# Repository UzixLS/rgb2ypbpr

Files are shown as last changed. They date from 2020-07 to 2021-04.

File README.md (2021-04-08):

## RGB to YPbPr simple converter

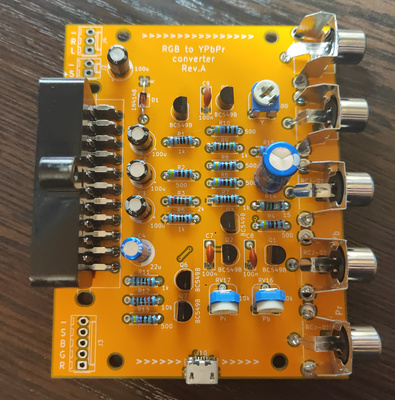
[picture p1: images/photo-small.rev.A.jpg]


Based on "Universal RGB-to-YPbPr/Component Encoder" by Steven Hanley (thesteve)

This schematic doesn't show perfect output picture quality, but uses cheap widely available parts.

Links:

https://www.pcenginefx.com/forums/index.php?topic=13231.0

https://www.sega-16.com/forum/showthread.php?28932-Universal-RGB-to-Component-Design

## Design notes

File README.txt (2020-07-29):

RGB to YPbPr simple converter

Based on "Universal RGB-to-YPbPr/Component Encoder" by Steven Hanley (thesteve)

Links:
https://www.pcenginefx.com/forums/index.php?topic=13231.0
https://www.sega-16.com/forum/showthread.php?28932-Universal-RGB-to-Component-Design

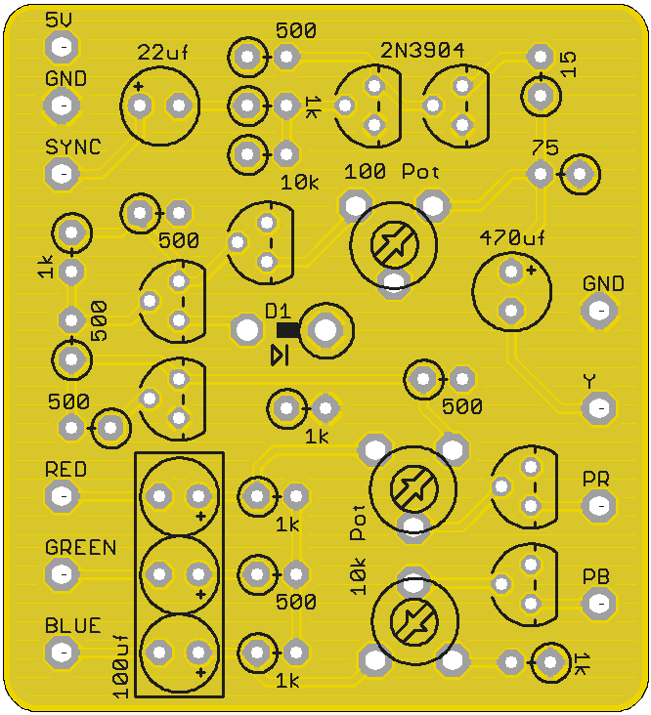
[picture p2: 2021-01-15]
doc/references/top.png

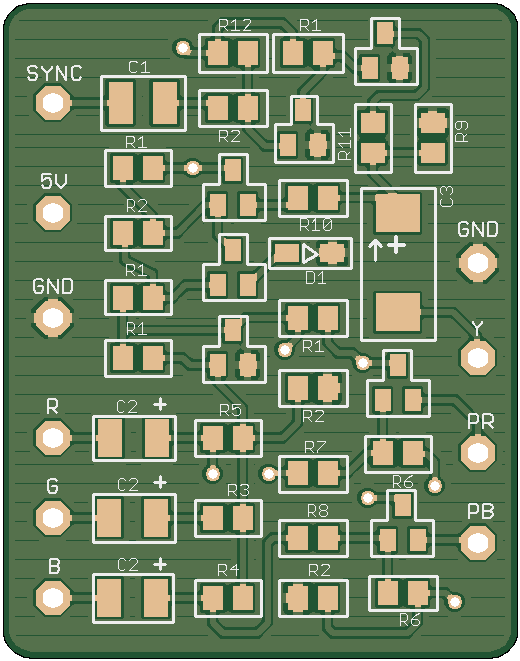
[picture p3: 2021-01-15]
doc/references/topnew.png

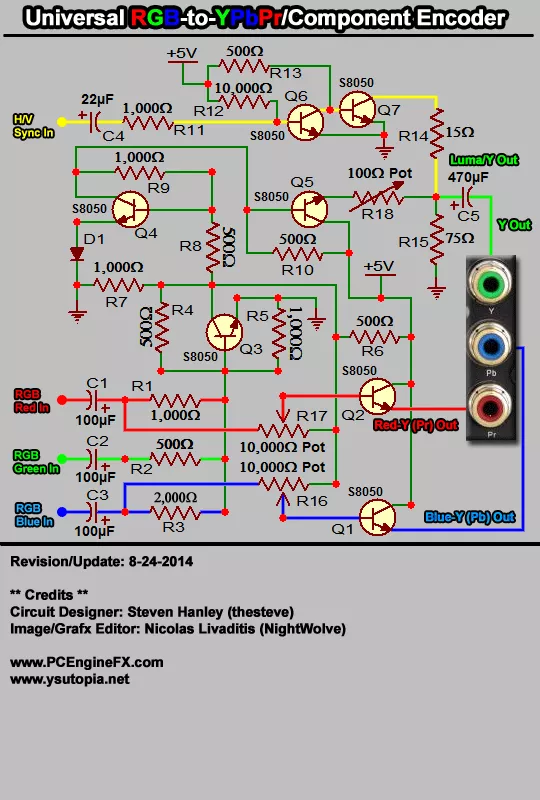
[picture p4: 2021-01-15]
doc/references/RGB-to-YPbPr-Circuit.webp

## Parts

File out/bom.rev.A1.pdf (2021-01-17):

Designator | Package | Designation | Quantity
C1,C2,C3,C6 | CP_Radial_D6.3mm_P2.50mm | 100u | 4
C4 | CP_Radial_D6.3mm_P2.50mm | 22u | 1
C5 | CP_Radial_D6.3mm_P2.50mm | 470u | 1
C7,C8,C9 | C_Disc_D7.0mm_W2.5mm_P5.00mm | 100n | 3
D1 | D_T-1_P10.16mm_Horizontal | 1N4148 | 1
J1 | SCART | | 1
J10 | USB_Micro-B_Molex-105017-0001 | USB_B_Micro | 1
J3 | Molex_KK-254_AE-6410-05A_1x05_P2.54mm_Vertical | Conn_01x05 | 1
J4 | Molex_KK-254_AE-6410-05A_1x05_P2.54mm_Vertical | Conn_01x03 | 1
J5,J6,J7,J8,J9 | CUI_RCJ-01X-WIDE | RCJ-014 | 5
JP1 | PinHeader_1x02_P2.54mm_Vertical | Jumper | 1
Q1,Q2,Q3,Q4,Q5,Q6,Q7 | TO-92 | BC549B | 7
R1,R5,R7,R9,R11 | R_Axial_DIN0207_L6.3mm_D2.5mm_P7.62mm_H orizontal | 1k | 5
R12 | R_Axial_DIN0207_L6.3mm_D2.5mm_P7.62mm_H orizontal | 10k | 1
R14 | R_Axial_DIN0207_L6.3mm_D2.5mm_P7.62mm_H orizontal | 15 | 1
R15 | R_Axial_DIN0207_L6.3mm_D2.5mm_P7.62mm_H orizontal | 75 | 1
R2,R4,R6,R8,R10,R13 | R_Axial_DIN0207_L6.3mm_D2.5mm_P7.62mm_H orizontal | 500 | 6
R3 | R_Axial_DIN0207_L6.3mm_D2.5mm_P7.62mm_H orizontal | 2k | 1
RV16,RV17 | Potentiometer_Runtron_RM-065_Vertical | 10k | 2
RV18 | Potentiometer_Runtron_RM-065_Vertical | 100 | 1

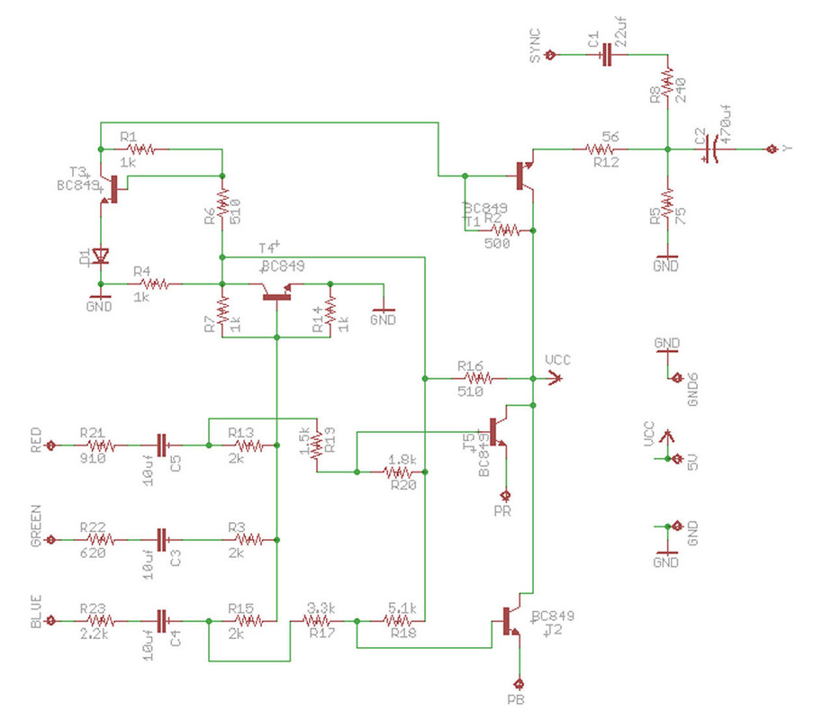
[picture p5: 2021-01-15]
doc/references/RGB_to_Component_Genesis.jpg

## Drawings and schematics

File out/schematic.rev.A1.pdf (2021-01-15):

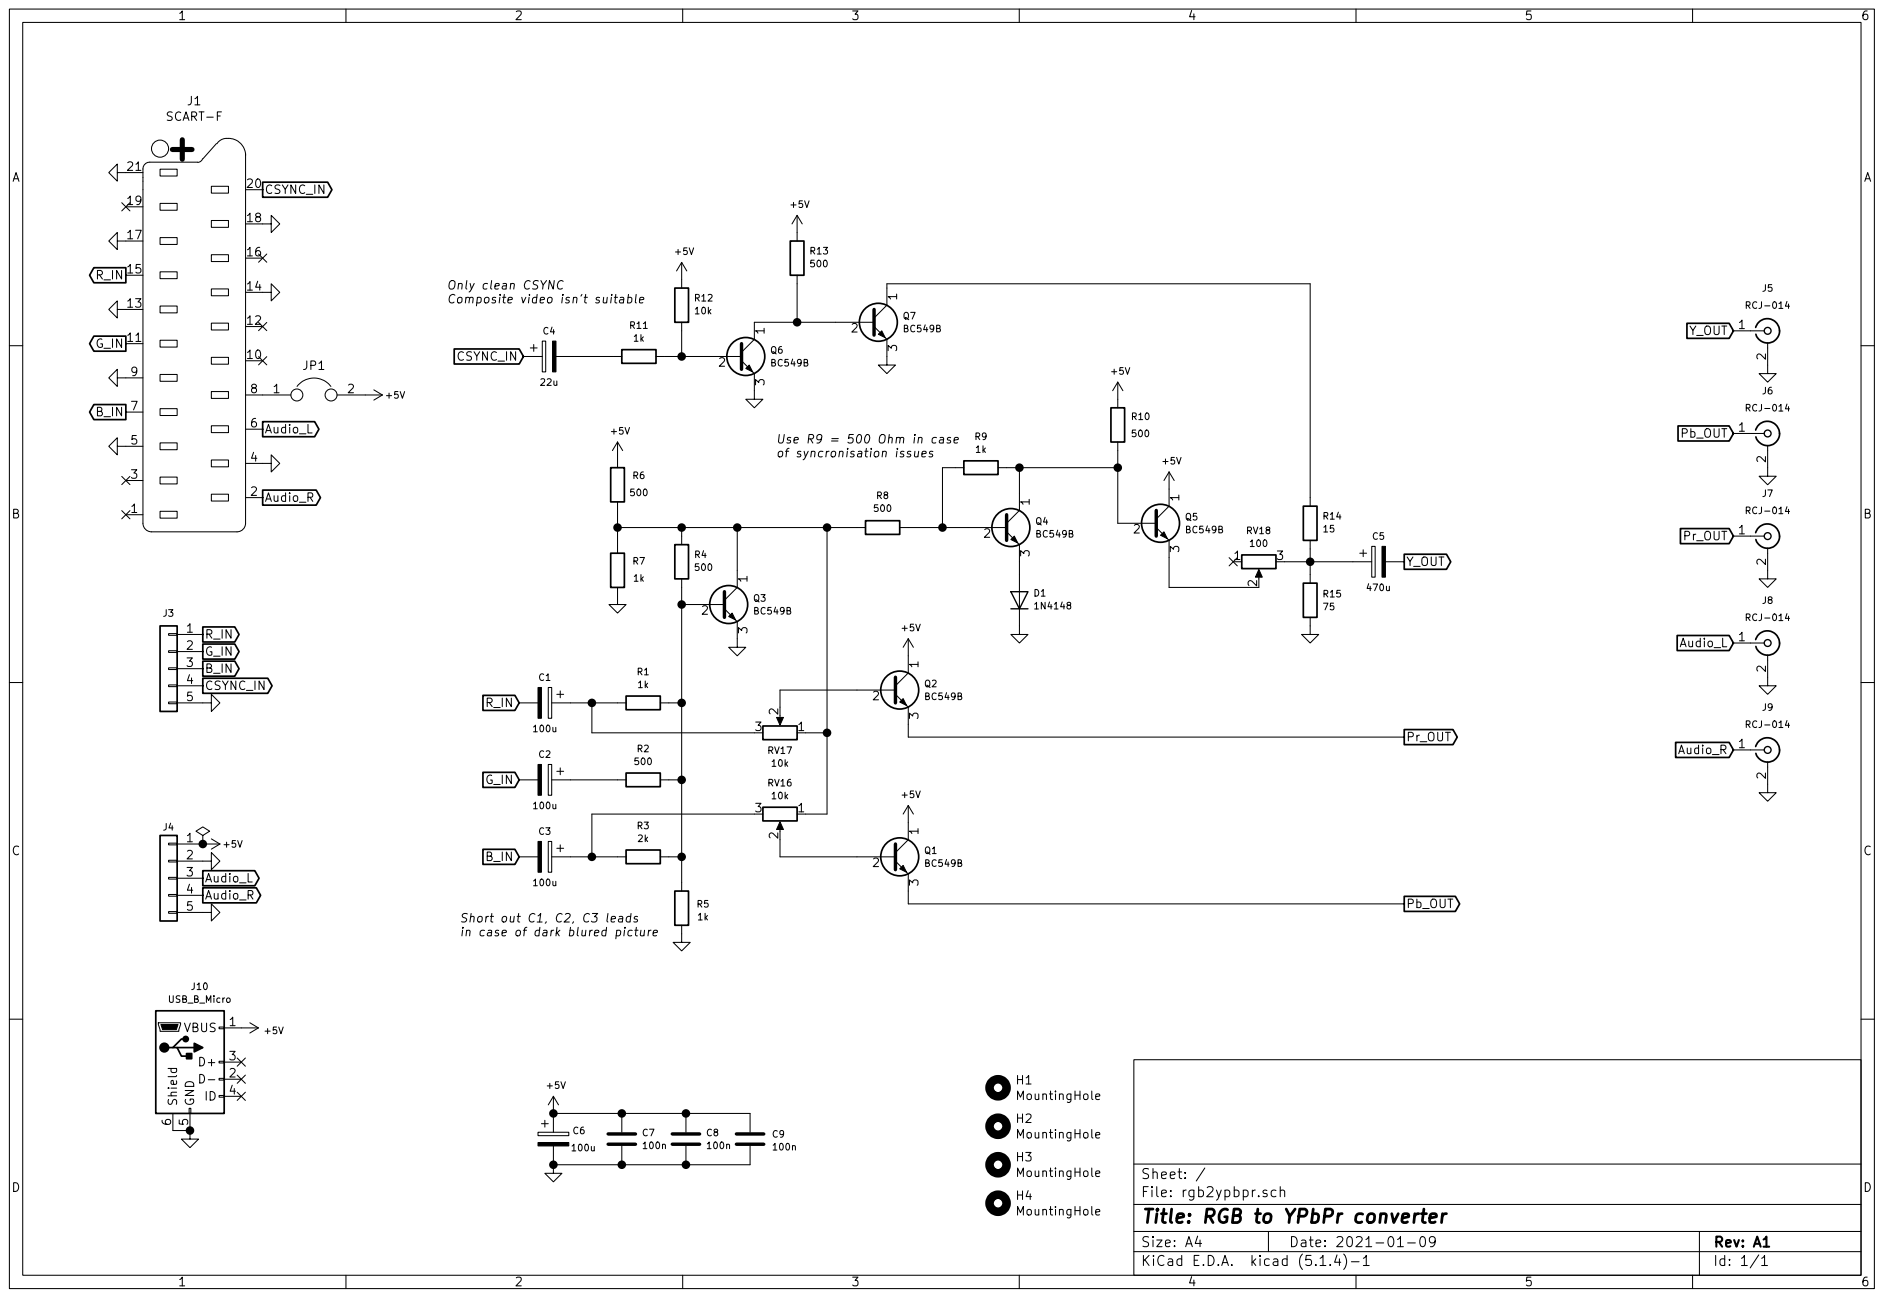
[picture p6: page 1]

of syncronisation issues Short out C1, C2, C3 leads

in case of dark blured picture

File: rgb2ypbpr.sch Sheet: /
Id: 1/1 Title: RGB to YPbPr converter

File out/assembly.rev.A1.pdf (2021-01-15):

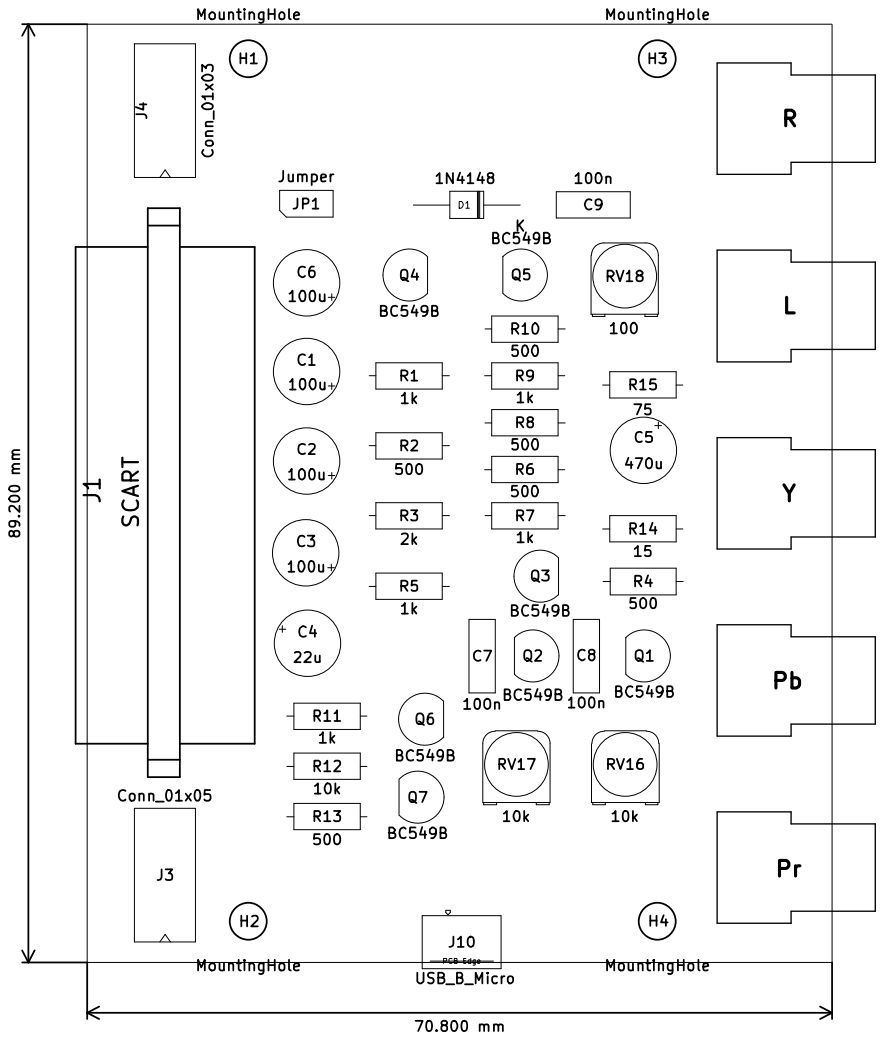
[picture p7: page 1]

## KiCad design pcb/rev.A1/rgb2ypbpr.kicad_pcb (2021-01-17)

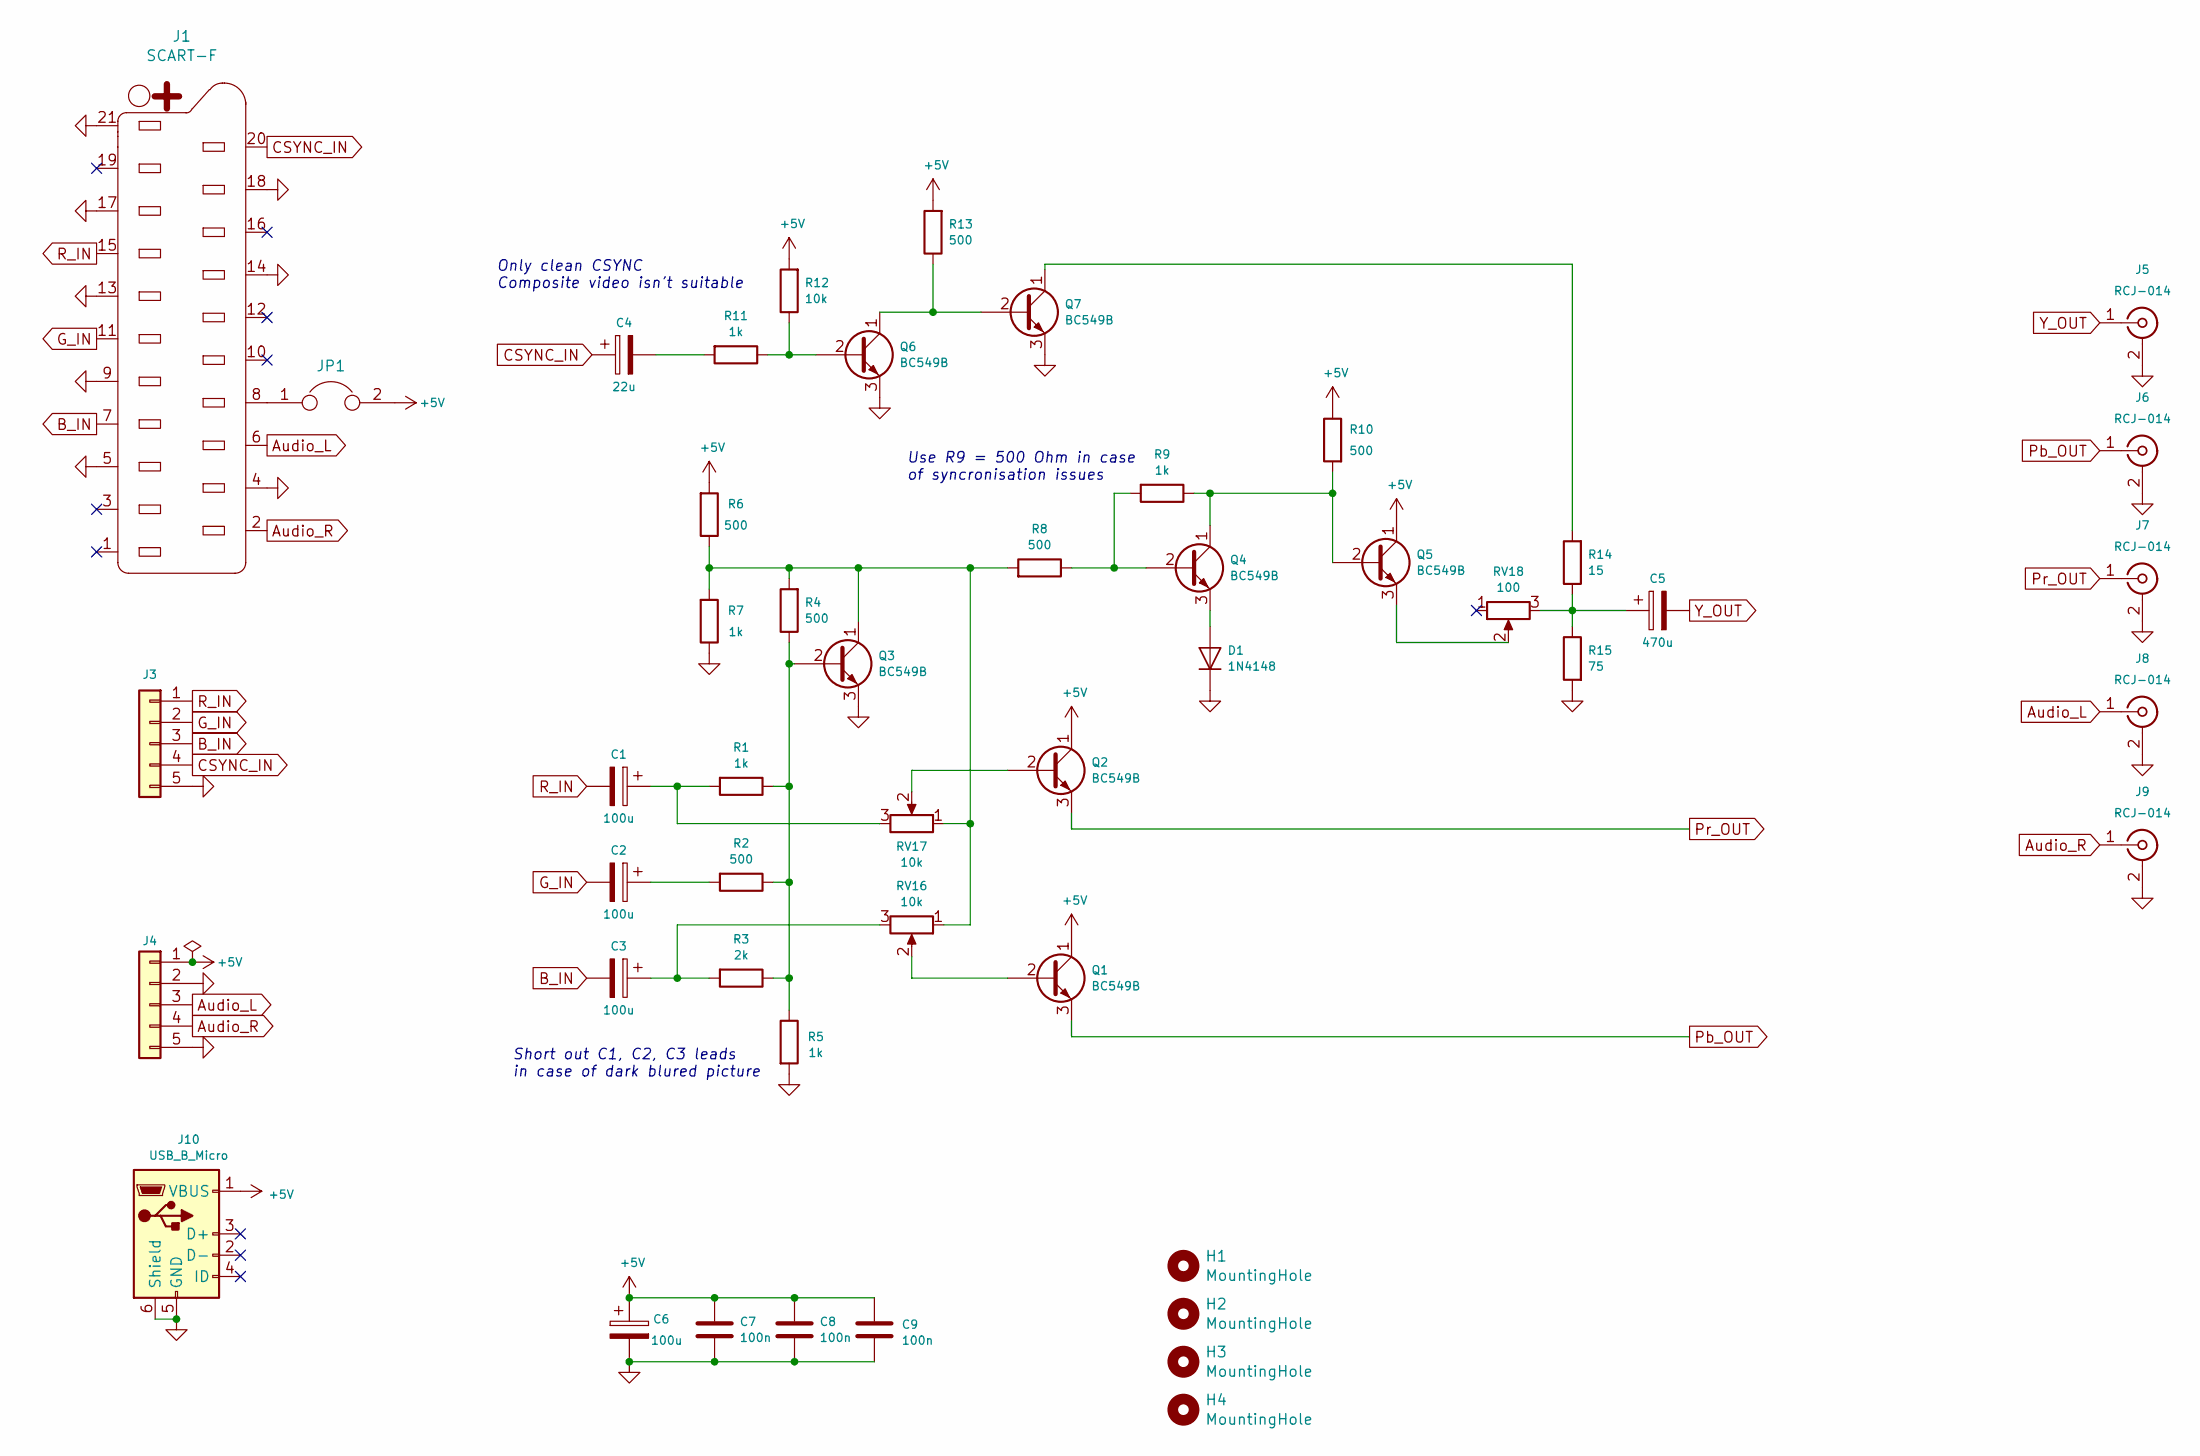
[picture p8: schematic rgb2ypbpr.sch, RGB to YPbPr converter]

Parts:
C1, C2, C3, C6: 100u; CP_Radial_D6.3mm_P2.50mm
C4: 22u; CP_Radial_D6.3mm_P2.50mm
C5: 470u; CP_Radial_D6.3mm_P2.50mm
C7, C8, C9: 100n; C_Disc_D7.0mm_W2.5mm_P5.00mm
D1: 1N4148; D_T-1_P10.16mm_Horizontal
H1, H2, H3, H4: MountingHole; MountingHole_3.2mm_M3
J1: SCART-F; SCART
J3: Conn_01x05; Molex_KK-254_AE-6410-05A_1x05_P2.54mm_Vertical
J4: Conn_01x03; Molex_KK-254_AE-6410-05A_1x05_P2.54mm_Vertical
J5, J6, J7, J8, J9: RCJ-014; CUI_RCJ-01X-WIDE
J10: USB_B_Micro; USB_Micro-B_Molex-105017-0001
JP1: Jumper; PinHeader_1x02_P2.54mm_Vertical
Q1, Q2, Q3, Q4, Q5, Q6, Q7: BC549B; TO-92
R1, R5, R7, R9, R11: 1k; R_Axial_DIN0207_L6.3mm_D2.5mm_P7.62mm_Horizontal
R2, R4, R6, R8, R10, R13: 500; R_Axial_DIN0207_L6.3mm_D2.5mm_P7.62mm_Horizontal
R3: 2k; R_Axial_DIN0207_L6.3mm_D2.5mm_P7.62mm_Horizontal
R12: 10k; R_Axial_DIN0207_L6.3mm_D2.5mm_P7.62mm_Horizontal
R14: 15; R_Axial_DIN0207_L6.3mm_D2.5mm_P7.62mm_Horizontal
R15: 75; R_Axial_DIN0207_L6.3mm_D2.5mm_P7.62mm_Horizontal
RV16, RV17: 10k; Potentiometer_Runtron_RM-065_Vertical
RV18: 100; Potentiometer_Runtron_RM-065_Vertical

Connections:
+5V: C6.1, C7.1, C8.1, C9.2, J4.1, J10.1 (VBUS), JP1.2, Q1.1 (C), Q2.1 (C), Q5.1 (C), R6.2, R10.1, R12.2, R13.2
Audio_L: J1.6, J4.3, J8.1 (In)
Audio_R: J1.2, J4.4, J9.1 (In)
B_IN: C3.2, J1.7, J3.3
CSYNC_IN: C4.1, J1.20, J3.4
GND: C6.2, C7.2, C8.2, C9.1, D1.1 (K), J1.4, J1.5, J1.9, J1.13, J1.14, J1.17, J1.18, J1.21, J3.5, J4.2, J4.5, J5.2 (Ext), J6.2 (Ext), J7.2 (Ext), J8.2 (Ext), J9.2 (Ext), J10.5 (GND), J10.6 (Shield), Q3.3 (E), Q6.3 (E), Q7.3 (E), R5.2, R7.1, R15.2
G_IN: C2.2, J1.11, J3.2
unnamed: C1.1, R1.2, RV17.3
unnamed: C2.1, R2.2
unnamed: C3.1, R3.2, RV16.3
unnamed: C4.2, R11.2
unnamed: C5.1, R14.1, R15.1, RV18.3
unnamed: D1.2 (A), Q4.3 (E)
unnamed: J1.8, JP1.1
unnamed: Q1.2 (B), RV16.2
unnamed: Q2.2 (B), RV17.2
unnamed: Q3.1 (C), R4.2, R6.1, R7.2, R8.2, RV16.1, RV17.1
unnamed: Q3.2 (B), R1.1, R2.1, R3.1, R4.1, R5.1
unnamed: Q4.1 (C), Q5.2 (B), R9.1, R10.2
unnamed: Q4.2 (B), R8.1, R9.2
unnamed: Q5.3 (E), RV18.2
unnamed: Q6.1 (C), Q7.2 (B), R13.1
unnamed: Q6.2 (B), R11.1, R12.1
unnamed: Q7.1 (C), R14.2
Pb_OUT: J6.1 (In), Q1.3 (E)
Pr_OUT: J7.1 (In), Q2.3 (E)
R_IN: C1.2, J1.15, J3.1
Y_OUT: C5.2, J5.1 (In)

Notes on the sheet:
Use R9 = 500 Ohm in case of syncronisation issues
Short out C1, C2, C3 leads in case of dark blured picture
Only clean CSYNC Composite video isn't suitable

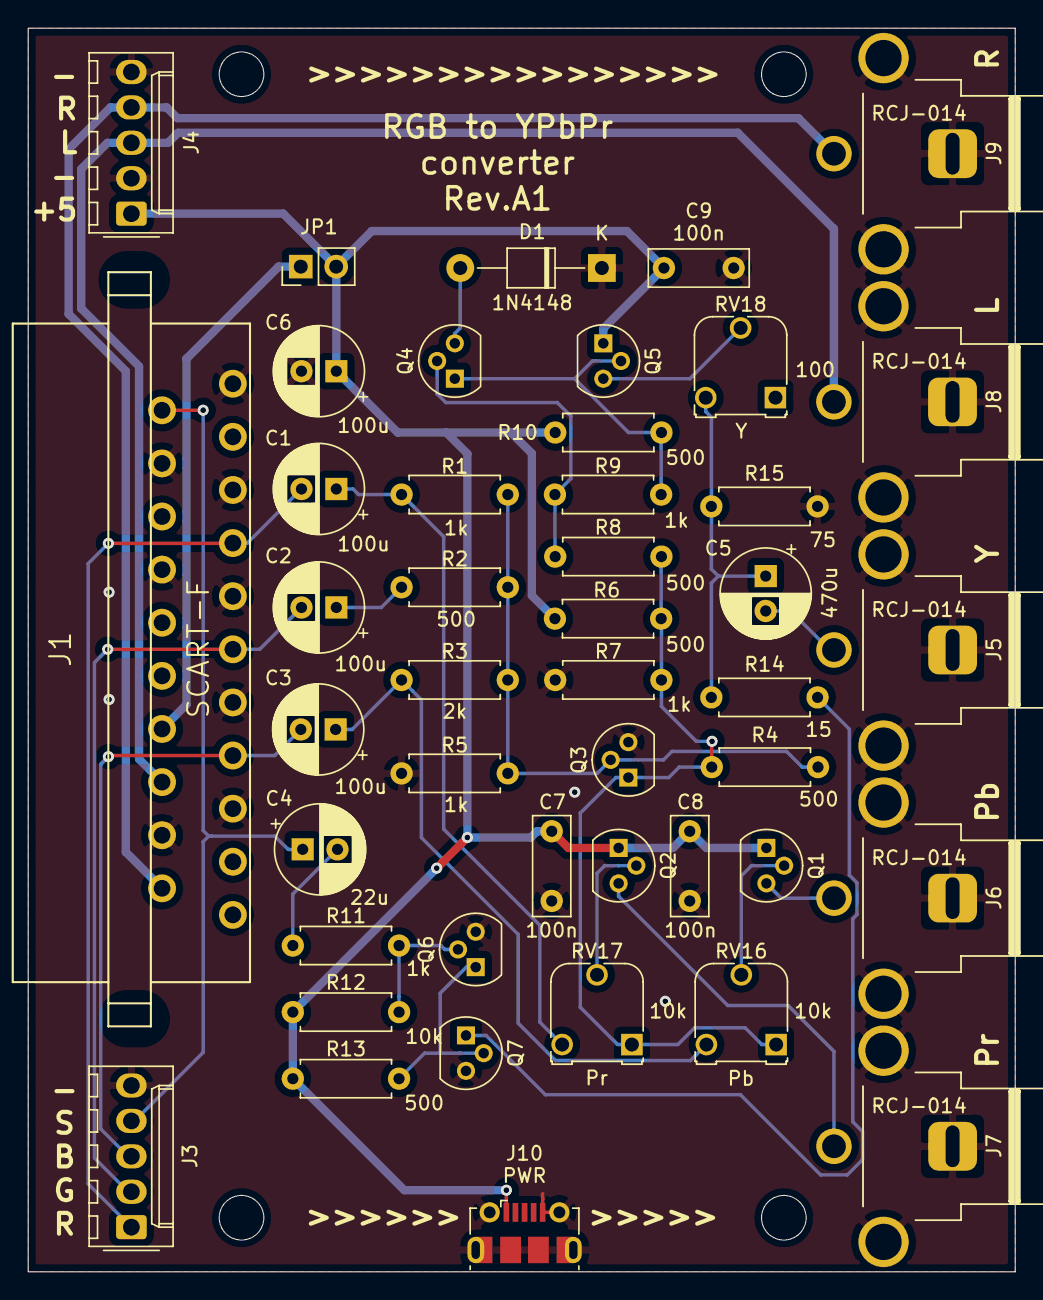
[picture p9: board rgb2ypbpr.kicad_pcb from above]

Board: 2 copper layers, 70.8 x 89.2 mm, 49 parts (0 on the bottom side), 28 nets.

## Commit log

2021-01-15 add rev.A pcb
    [rgb2ypbpr.kicad_pcb, rgb2ypbpr.sch]
2021-01-15 add ltspice circuit
2021-01-15 add rev.A1 pcb
    [rgb2ypbpr.kicad_pcb, rgb2ypbpr.sch]
2021-01-17 pcb rev.A1: replace TO-92_Inline footprint with TO-92
    [rgb2ypbpr.kicad_pcb, rgb2ypbpr.sch]
2021-04-08 update readme: use direct link to pcb image
